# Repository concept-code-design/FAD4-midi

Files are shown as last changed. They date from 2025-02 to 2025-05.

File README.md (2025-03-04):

# FAD4-midi

Fad 4 is a USB MIDI controller with 4 faders

The device sports a USB type-C connector and requires no device drivers on Mac or PC.

The faders (slider potentiometers) can be configured (via MIDI messages, or the configurator) to produce CC codes.
The device uses a modified midi library for CH55x devices made by mi:muz 

## Configuring the sliders
Configuration is easy with midiutil.py

start prog
./midiutil.py -d 1 -w 186 102 42
returns [185, 102, 42]

end prog
./midiutil.py -d 1 -w 186 102 43

get module type
./midiutil.py -d 1 -w 186 102 44
returns: (10, 103, INSTRUMENT_TYPE);

get firmware version
./midiutil.py -d 1 -w 186 102 45
returns (10, 104, FW_VERSION) 10 for version 1.0

show configuration
./midiutil.py -d 1 -w 186 102 46
returns the config of each of the 4 sliders

set MIDI channel 
./midiutil.py -d 1 -w 186 102 48
returns (10, 106, MIDIChannel)

reboot in firmware update mode
./midiutil.py -d 1 -w 186 102 49

programming sliders
./midiutil.py -d 1 -w 186 102 42

./midiutil.py -d 1 -w 186 1 9

./midiutil.py -d 1 -w 186 2 15

./midiutil.py -d 1 -w 186 3 21

./midiutil.py -d 1 -w 186 4 22

./midiutil.py -d 1 -w 186 102 43

sets slider 1 to CC 9, 2 to 15 etc

## Links & References

* [mi:muz:ch55x Tiny USB MIDI Library for Ch55xduino](https://github.com/mimuz/mimuz-ch55x)
* [python-rtmidi](http://pypi.python.org/pypi/python-rtmidi/)
* [midiutil](https://github.com/sourcebox/midiutil)

# License

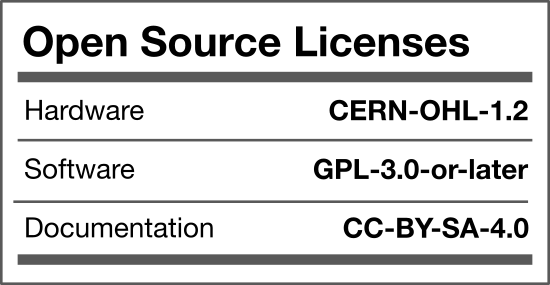
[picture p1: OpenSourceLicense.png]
OpenSourceLicense


Concept & Code invests time and resources providing this open source design, please support them and open-source hardware by purchasing products from Etsy or Tindie!

Designed by Ronald Leenes.

Firmware released under an GNU AGPL v3.0 license. See the LICENSE file for more information.

Hardware released under an CERN Open Hardware Licence v1.2. See the LICENSE_HARDWARE file for more information.

February 2025

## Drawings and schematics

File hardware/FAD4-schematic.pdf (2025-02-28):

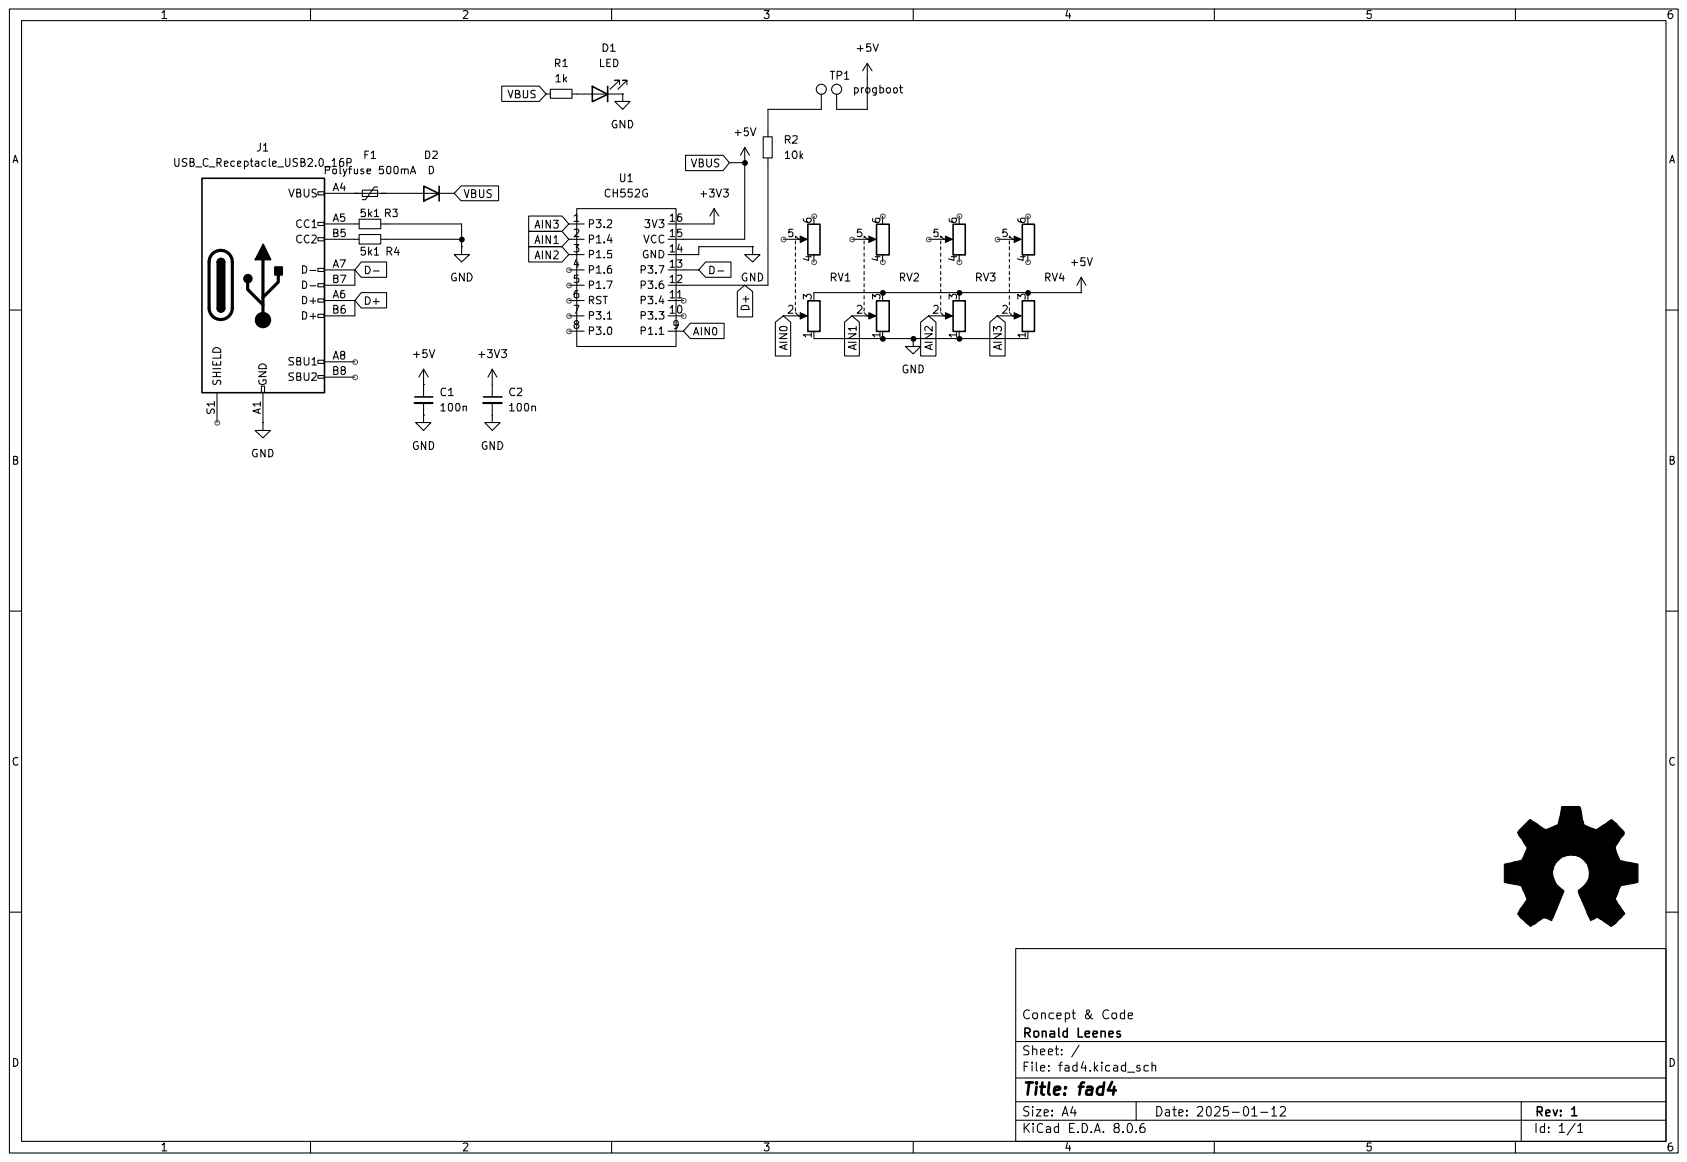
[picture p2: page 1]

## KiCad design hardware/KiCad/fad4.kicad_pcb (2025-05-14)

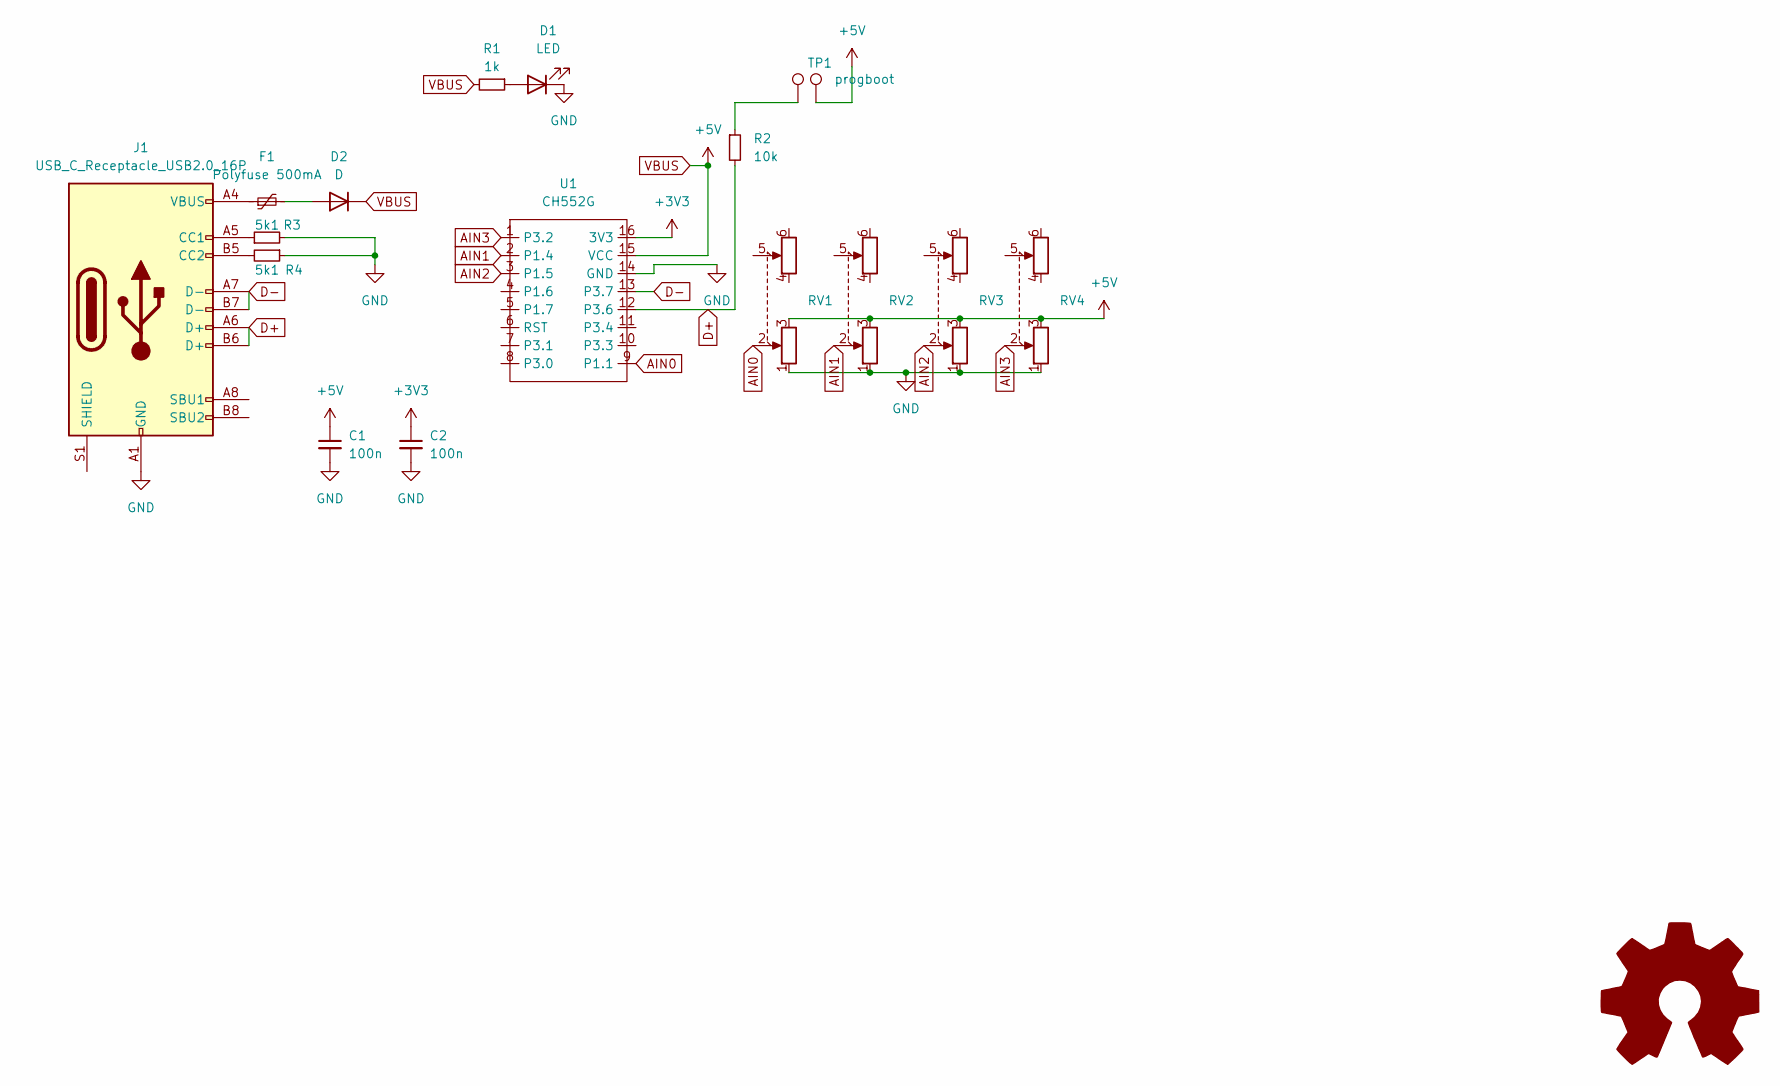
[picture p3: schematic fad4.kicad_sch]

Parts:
C1, C2: 100n; C_1206_3216Metric
D1: LED; LED_0603_1608Metric
D2: D; D_SMA_Handsoldering
F1: Polyfuse 500mA; Fuse_1210_3225Metric
J1: USB_C_Receptacle_USB2.0_16P; USB_C_Receptacle_GCT_USB4105-xx-A_16P_TopMnt_Horizontal
R1: 1k; R_1206_3216Metric
R2: 10k; R_1206_3216Metric
R3, R4: 5k1; R_1206_3216Metric
RV1, RV2, RV3, RV4: R_Potentiometer_Dual; B103 slider 4560mm
TP1, TP2: progboot; TestPoint_Pad_1.5x1.5mm
U1: CH552G

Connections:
+3V3: C2.1, U1.16 (3V3)
AIN0: RV1.2, U1.9 (P1.1)
AIN1: RV2.2, U1.2 (P1.4)
AIN2: RV3.2, U1.3 (P1.5)
AIN3: RV4.2, U1.1 (P3.2)
D+: J1.A6 (D+), J1.B6 (D+), R2.2, U1.12 (P3.6)
D-: J1.A7 (D-), J1.B7 (D-), U1.13 (P3.7)
GND: C1.2, C2.2, D1.1 (K), J1.A1 (GND), J1.A12 (GND), J1.B1 (GND), J1.B12 (GND), R3.2, R4.1, RV1.1, RV2.1, RV3.1, RV4.1, U1.14 (GND)
unnamed: D1.2 (A), R1.1
unnamed: D2.2 (A), F1.2
unnamed: F1.1, J1.A4 (VBUS), J1.A9 (VBUS), J1.B4 (VBUS), J1.B9 (VBUS)
unnamed: J1.A5 (CC1), R3.1
unnamed: J1.B5 (CC2), R4.2
unnamed: R2.1, TP1.1
VBUS: C1.1, D2.1 (K), R1.2, RV1.3, RV2.3, RV3.3, RV4.3, TP2.1, U1.15 (VCC)

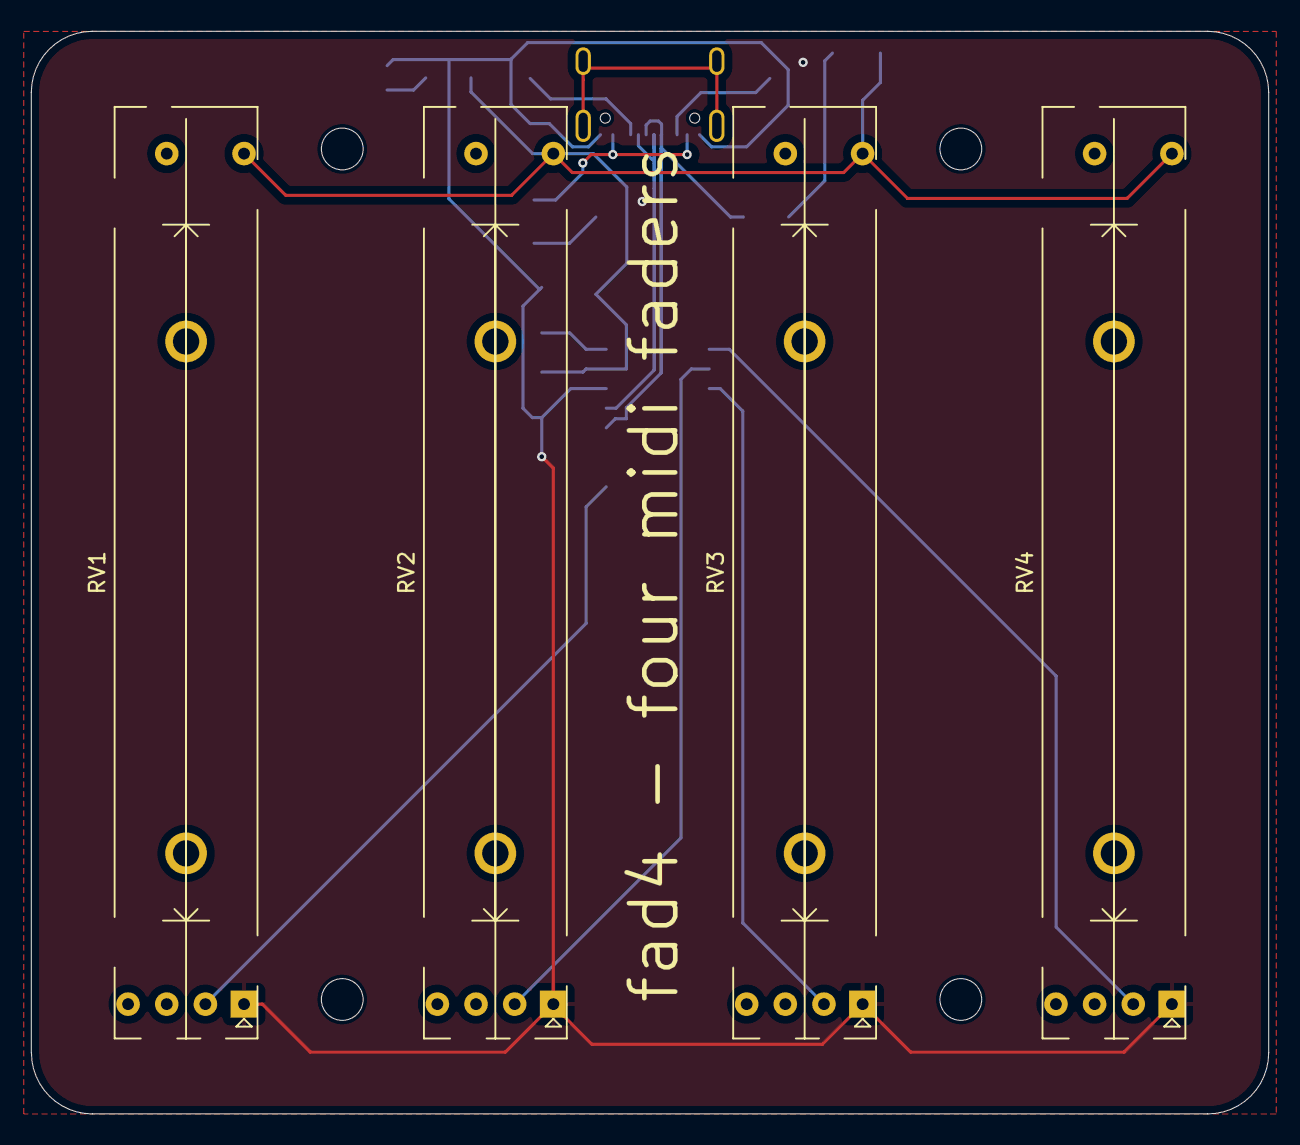
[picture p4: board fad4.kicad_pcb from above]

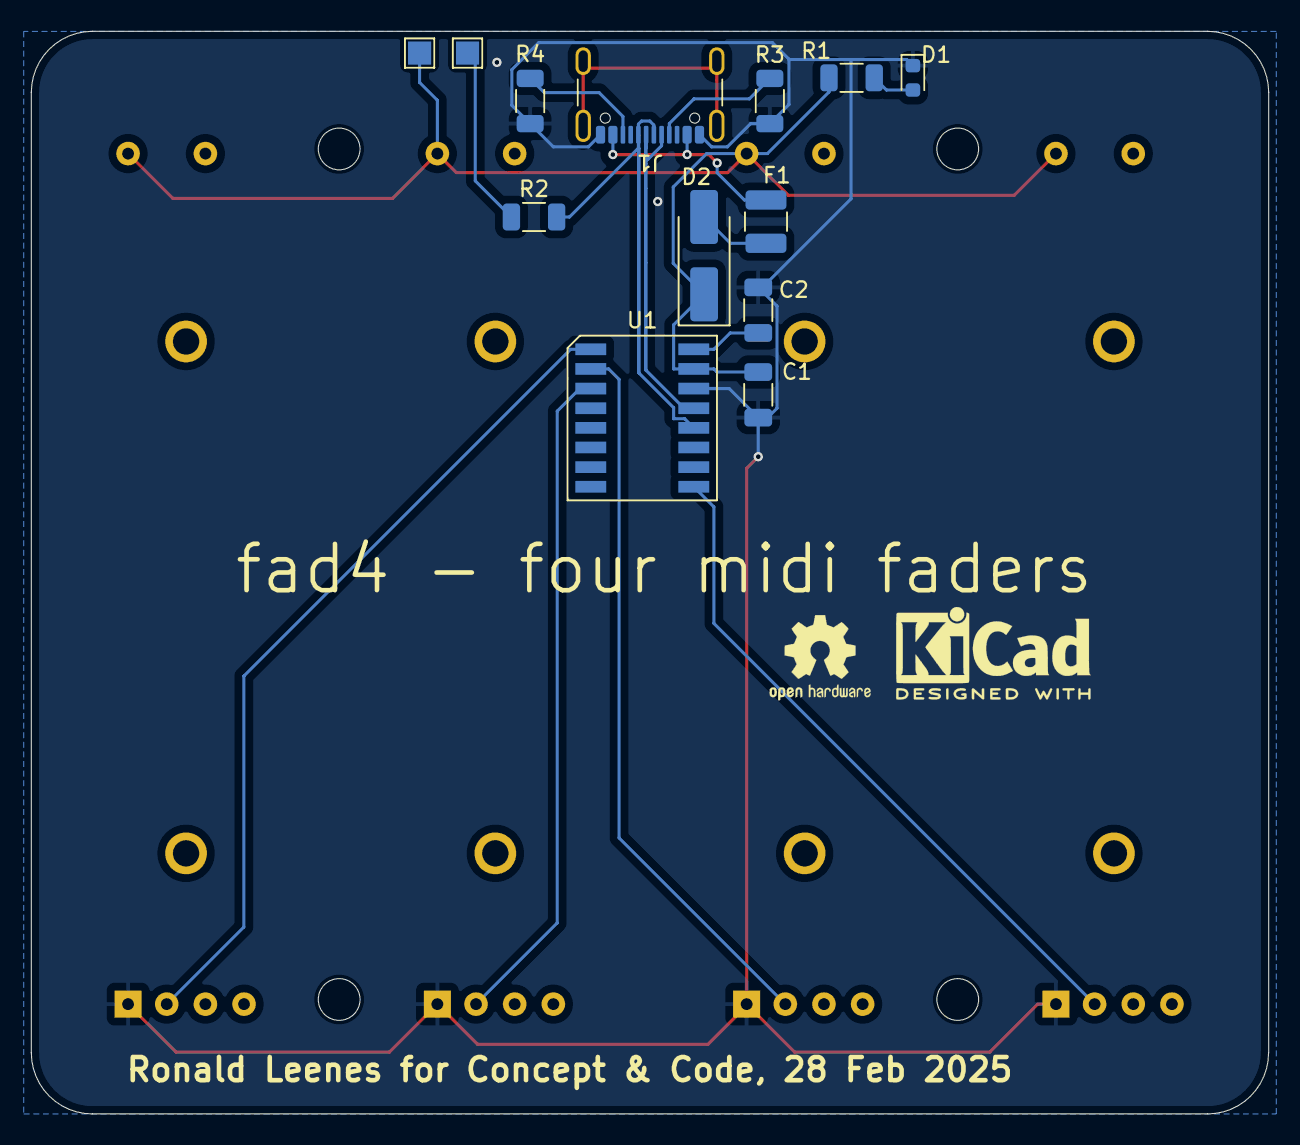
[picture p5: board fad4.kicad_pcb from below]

Board: 2 copper layers, 80.0 x 70.0 mm, 21 parts (13 on the bottom side), 15 nets.

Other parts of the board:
h1, h2, h3, h4: MountingHole_2.7mm_M2.5_DIN965

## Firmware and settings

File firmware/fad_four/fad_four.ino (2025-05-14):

// ===================================================================================
// Project:   Fader four (Fad4)
// Version:   v1.0
// Year:      2025
// Author:    Ronald Leenes
// Github:    https://github.com/concept-code-design/FAD4-midi
// License:   http://creativecommons.org/licenses/by-sa/3.0/
// ===================================================================================
//

#ifndef USER_USB_RAM
#error "This example needs to be compiled with a USER USB setting"
#endif

#include "config.h"
#include "mimuz-ch55x.h"

void onCTLChange(uint8_t ch, uint8_t note, uint8_t vel);
void writeEEPROM();
void readEEPROM();
void PROGBOOT_now();

// hardware
#define INSTRUMENT_TYPE 40 // this is a Fad4
#define FW_VERSION      10 // version 1.0

__xdata const uint8_t faderPin[] = {11, 14, 15, 32};
__xdata uint8_t previousValue[] = {0,0,0,0};
__xdata uint8_t sensorValue = 0;
__xdata uint8_t MIDI_CHANNEL = 10;  // defaults to channel 10
__xdata uint8_t CC[4];
__xdata const uint8_t hyst = 2; //hysteresis
#define PLAY_MODE 0
#define PROG_MODE 1
#define PROG_DONE 2
__xdata uint8_t currentMode = PLAY_MODE;

void PROGBOOT_now(void){
  USB_CTRL = 0;
  EA = 0;
  TMOD = 0;
  __asm lcall #BOOT_LOAD_ADDR __endasm;
}

void setup() {
  for (int i = 0 ; i < 4; i++) pinMode(faderPin[i],INPUT); 
  for (int i = 0 ; i < 4; i++) previousValue[i] = map(analogRead(faderPin[i]), 0, 255, 0, 127);
  setHdlCtlChange(onCTLChange);
  USBInit();
  readEEPROM();
}

void loop() {
  for (int i = 0 ; i < 4; i++) {
    sensorValue = analogRead(faderPin[i]);
    if ((sensorValue > (previousValue[i] + hyst)) || (sensorValue < (previousValue[i] - hyst))){
      sendCtlChange(2 , CC[i], sensorValue); //MIDI_CHANNEL - 1
      previousValue[i] = sensorValue;
    }
  }
    processMidiMessage();
}

void readEEPROM(){
  MIDI_CHANNEL = eeprom_read_byte(0);
  for (int i = 0; i < 4; i++) {
    CC[i] = eeprom_read_byte(1+i);
  }
}

void writeEEPROM(){
  eeprom_write_byte(0, MIDI_CHANNEL);
  for (int i = 0; i < 4; i++) {
    eeprom_write_byte(1+i, CC[i]);
  }
}

void onCTLChange(uint8_t ch, uint8_t note, uint8_t vel) {
  __xdata uint8_t type = 0;
  __xdata uint8_t key = 0;
  ch = getChannel();
  note = getNote();
  vel =  getVel();
  type = note / 10;       
  key = (note % 10) - 1;  // we number keys from 1..7 (1..6 are keys, 7 is the encoder) 
  if ((ch == 10) && (note == 102)) {
    if (vel > 127)sendNoteOn(3, note, vel);
    switch (vel){
      case 42:
          currentMode = PROG_MODE; // enter configuration mode
          sendCtlChange(10, 102, 42);
          break;
      case 43:
          //currentMode = PROG_DONE;  //configuration done
          writeEEPROM();
          sendCtlChange(10, 102, 43);
          currentMode = PLAY_MODE;
          break;
      case 44:                    // return instrument tyoe
          sendCtlChange(10, 103, INSTRUMENT_TYPE);
          break;
      case 45:                    // return firmware version
          sendCtlChange(10, 104, FW_VERSION);
          break;
      case 46:                    // return current config
        for (int i = 0; i < 4; i++) sendCtlChange(10, i+1, CC[i]);
         break;
      case 48:                // return MIDI channel
        sendCtlChange(10, 106, MIDI_CHANNEL);
        break;
      case 49: // reboot in prog mode                            // update pixels
        PROGBOOT_now();     // jump to bootloader
        break;
      default:
        break;
    }
  }
 
  if (currentMode == PROG_MODE) {
        // handle regular keys
      if ((note > 0) && (note < 5)) CC[note-1] = vel;
        if (note == 5) {
          if ((vel > 0) && (vel < 16))  MIDI_CHANNEL = vel; else MIDI_CHANNEL = 1;
        }
  } 
}
